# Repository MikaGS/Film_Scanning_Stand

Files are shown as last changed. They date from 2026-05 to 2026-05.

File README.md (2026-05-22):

# Film Scanning Stand



A modular DIY film scanning stand for digitizing 35mm and medium format negatives using a mirrorless camera.

The system uses aluminium extrusions, a linear rail, leveling parts and a camera carrier. It is designed for repeatable alignment, precise camera height adjustment, and high-resolution scans of larger formats such as 6x7 and 6x12. 

## Features

- Adjustable camera height on linear rail
- Aluminium extrusion frame
- Mirrorless camera support
- Compatible with 35mm, 6x7 and 6x12 film
- Custom 3D-printed film holders
- Designed for stitched high-resolution scans
- Modular and repairable construction

## Current Status

Prototype / work in progress.
Stand is working, automation with steppers, etc. in progress

## Documentation

- [Build Guide](docs/build-guide.md)
- [Camera Setup and Calibration](docs/camera-setup.md)
- [Film Holders](docs/film-holders.md)
- [Parts List](bom/parts-list.md)

## License

This project is shared for personal, educational and non-commercial DIY use.

You may build, modify and share this project for non-commercial purposes, but you may not sell printed parts, kits, CAD files, drawings, assembled versions or derivatives of this design without written permission.

See [LICENSE.md](LICENSE.md) for details.

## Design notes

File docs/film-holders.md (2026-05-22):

# Film Holders

This document describes the film holder system used with the modular film scanning stand.

The holders are designed to keep the film flat, aligned and repeatable during camera scanning. Different holders can be used for 35mm film and medium format negatives such as 6x7 and 6x12.

## Design Goals

- Hold the film flat during scanning
- Keep the film plane repeatable
- Reduce reflections from the light source
- Allow accurate stitching of larger negatives
- Use simple 3D-printed parts
- Be easy to modify for different film formats

## Supported Formats

| Format | Notes |
|---|---|
| 35mm | Single-frame scanning |
| 6x7 | Medium format scanning |
| 6x12 | Stitched panoramic scanning |

## Holder Construction

The film holder consists of two main parts:

- a lower base part
- an upper clamping part

The lower part defines the film position and scanning window.  
The upper part holds the film down and helps keep it flat.

The two parts are aligned using metal pins.

## Alignment Pins

Metal pins are used to keep the film holder aligned between scans.

The first pair of pins defines the X-position.  
A second pair of pins helps control rotation while still allowing controlled tolerance in the Y-direction if needed.

This makes the holder repeatable while avoiding unnecessary stress on the printed parts or the film.

## Film Flatness

Film flatness is created by pressing the film between the upper and lower holder parts.

Screws can be used to apply light pressure.

The film should be held flat, but not so tightly that it scratches or bends.

## Scanning Window

The scanning window is smaller than the complete negative area in some holder versions.

This helps reduce unwanted reflections and improves contrast during scanning.

For stitched scans, the film can be scanned in multiple overlapping sections.

## 6x12 Scanning

The 6x12 holder is designed for stitched scanning.

Instead of capturing the whole negative in one image, the film is scanned in multiple overlapping shots. This allows higher resolution and better use of the camera sensor.

Typical workflow:

1. Place the film in the holder.
2. Align the first scanning position.
3. Capture the first image.
4. Move the camera or film holder to the next position.
5. Capture the overlapping image.
6. Repeat until the full negative is covered.
7. Stitch the images in software.

## Material

The holders are 3D printed.

Recommended materials:

- PETG
- ABS / ASA
- stiff carbon-filled filament

For this build, Extrudr GreenTEC Pro CF was used.

A matte black material is recommended to reduce reflections.

## Notes

Avoid glossy surfaces near the film or scanning window.

If reflections appear in the scan, reduce the window size, add matte black surfaces, or increase the distance between the film and reflective parts.

The holder design may need to be adjusted depending on the exact light source, camera setup and scanning format.

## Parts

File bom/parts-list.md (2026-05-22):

# Parts List

This list contains the main mechanical and printed parts required to build the modular film scanning stand.

Quantities and lengths may depend on the final CAD model and the desired scanning height.

## Main Components

| Part | Quantity | Notes |
|---|---:|---|
| Aluminium extrusion | as needed | Cut to the desired length |
| Linear rail, 300 mm | 1 | Mini linear rail with 2 carriage blocks |
| MGN12H carriage blocks | 2 | Usually included with the rail |
| Lead screw | 1 | Length depends on the CAD model |
| Lead screw nut | 2 | for precise movement |
| Lead screw coupling | 1 | For connecting the stepper motor to the lead screw |
| Bearing for lead screw | 1 | Used in the top bearing mount |
| Stepper motor | 1 | For height adjustment and holding force |
| Camera leveling plate | 1 | For fine camera alignment |
| Panorama head / panorama plate | optional | Useful for better leveling and rotational alignment |
| Arca-Swiss quick release clamp | optional | For easier camera mounting and removal |
| Base plate | 1 | Siebdruckplatte or another stable board |
| Black acrylic sheet | optional | For laser-cut covers, panels or finishing parts |

## Fasteners and Hardware

| Part | Quantity | Notes |
|---|---:|---|
| M3 screws | as needed | Used for linear rail and smaller printed parts |
| M4 screws | as needed | Used for medium-strength printed connections |
| M5 screws | as needed | Used for adapters to aluminium extrusion |
| M5 slot nuts / T-nuts | as needed | For mounting printed adapters to the aluminium extrusion |
| M5 × 6 mm wafer head screws | as needed | Low-profile mounting screws |
| M5 × 10 mm wafer head screws | as needed | For extrusion adapters or thicker printed parts |
| M4 × 8 mm wafer head screws | as needed | For printed parts or accessory mounting |
| 3/8" camera screws | as needed | For tripod plates, leveling plates or camera accessories |
| Heat-set inserts, M3/M4/M5 | as needed | I used short threaded inserts, e.g. CNC Kitchen inserts |

## 3D Printing

| Material | Notes |
|---|---|
| PETG | Easy to print, good general choice |
| ABS / ASA | Better heat resistance, harder to print |
| Extrudr GreenTEC Pro CF | Used for this build; stiff, carbon-filled material |
| Other stiff filament | Can be used if dimensions and strength are suitable |

## Printed Parts

| Printed Part | Notes |
|---|---|
| Linear rail adapters | Connect the rail to the aluminium extrusion |
| Top bearing mount | Holds the top lead screw bearing |
| Top bearing lid | Secures the bearing in place |
| Bottom support | Lower support for the lead screw / extrusion |
| Camera carrier, first half | Mounts to the linear rail carriages |
| Camera carrier, second half | Holds the leveling plate / camera mount |
| Optional covers or spacers | Depending on the final CAD design |

## Optional Laser-Cut Parts

| Part | Material | Notes |
|---|---|---|
| Side panels | Black acrylic | Optional visual or structural finishing parts |
| Covers | Black acrylic | Can be used to hide mechanics or improve appearance |
| Alignment plates | Acrylic or plywood | Optional aids for assembly and calibration |

## Notes

Check the final CAD model before ordering the lead screw, aluminium extrusion and acrylic parts.

Some screw lengths may need to be adjusted depending on the printed part thickness, insert depth and accessory stack-up.

For the base plate, a stable and flat material is recommended. A Siebdruckplatte or another rigid wooden board works well.

## Related Parts Lists

- [Film Holder Parts List](film-holder-parts-list.md)

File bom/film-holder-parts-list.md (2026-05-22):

# Film Holder Parts List

This list contains the parts required for the 3D-printed film holders.

Quantities may depend on the number of film holders and supported formats.

## Main Components

| Part | Quantity | Notes |
|---|---:|---|
| 3D-printed film holder parts | as needed | Lower base and upper clamping parts |
| 2 mm × 22 mm cylindrical pins | as needed | Used for alignment between holder parts |
| M4 heat-set inserts | as needed | I used CNC Kitchen threaded inserts |
| M4 screws | as needed | Used to clamp or assemble the holder |
| M4 × 8 mm wafer head screws | as needed | Low-profile option for the film holder |
| Filament | as needed | PETG, ABS, ASA or stiff carbon-filled filament |

## Recommended Material

For this build, **Extrudr GreenTEC Pro CF** was used.

A matte black, stiff material is recommended because it helps reduce reflections around the scanning window and keeps the holder dimensionally stable.

## Notes

The cylindrical pins are used for repeatable alignment of the upper and lower film holder parts.

Screw lengths may need to be adjusted depending on the printed part thickness and the depth of the heat-set inserts.

Avoid glossy materials near the film window, since they can cause reflections during scanning.

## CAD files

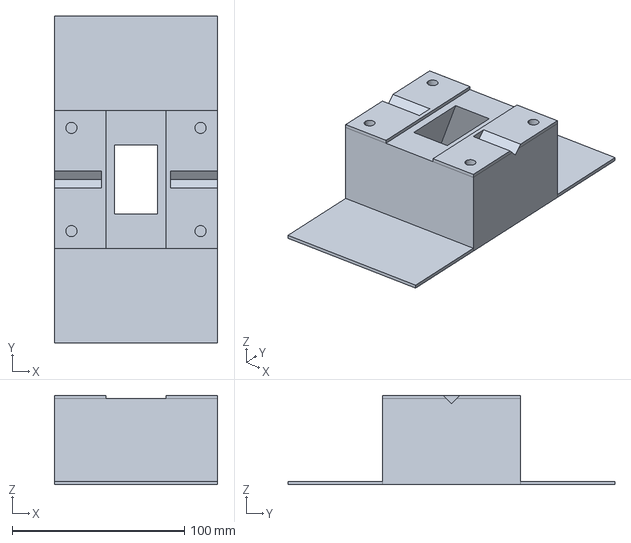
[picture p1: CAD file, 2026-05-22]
3D files/35mm_Holder_1.stp
95.0 x 190.0 x 52.0 mm

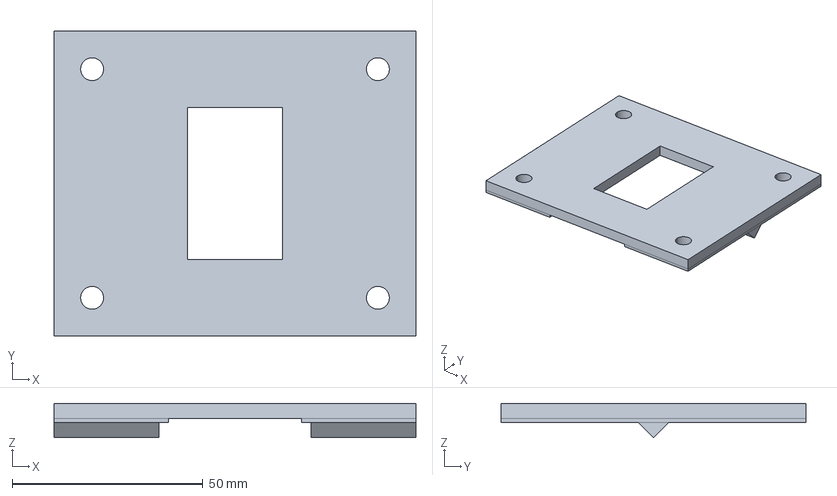
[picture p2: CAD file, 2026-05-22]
3D files/35mm_Holder_2.stp
95.0 x 80.0 x 9.00 mm

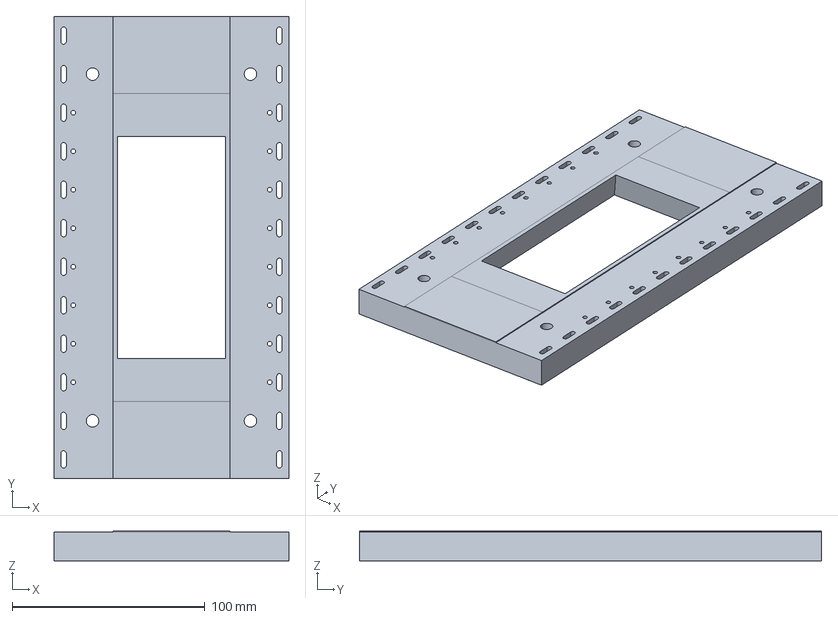
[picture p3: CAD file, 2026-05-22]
3D files/6x12_Holder_2.stp
122.0 x 240.0 x 15.5 mm

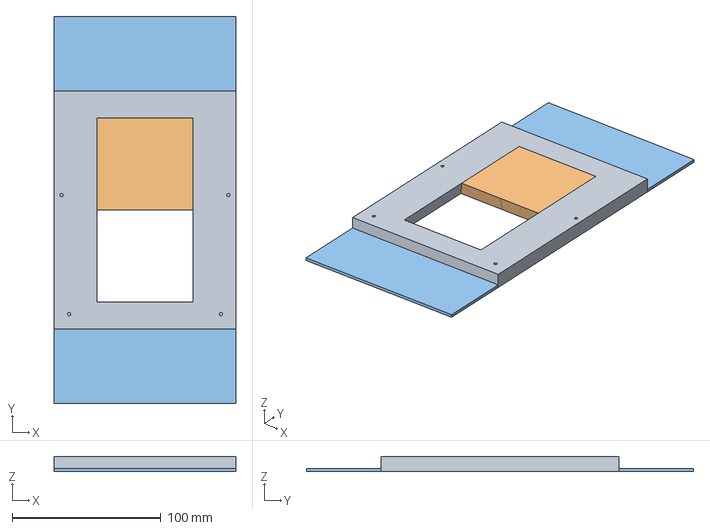
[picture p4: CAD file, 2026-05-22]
3D files/6x12_Holder_1.stp
122.0 x 260.0 x 10.0 mm

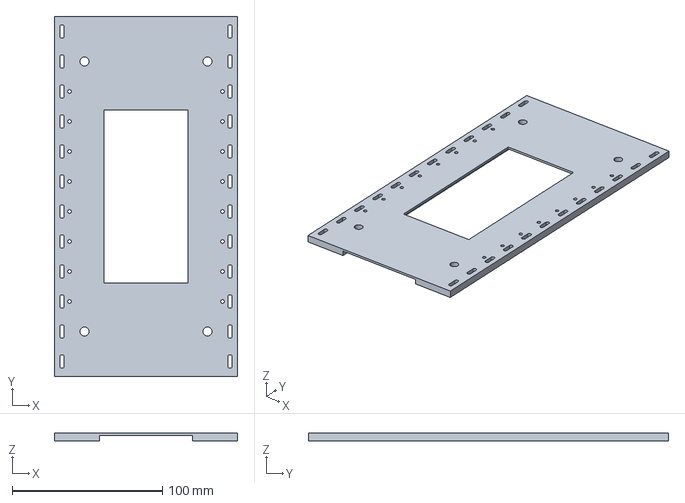
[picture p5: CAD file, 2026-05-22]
3D files/6x12_Holder_3.stp
122.0 x 240.0 x 5.00 mm

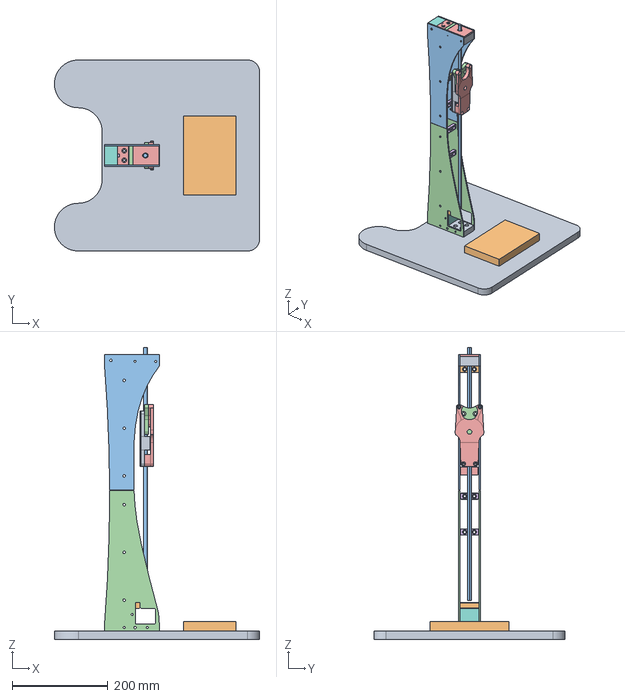
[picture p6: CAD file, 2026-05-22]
3D files/Scanning_Stand_V1.stp
429.6 x 400.0 x 611.5 mm

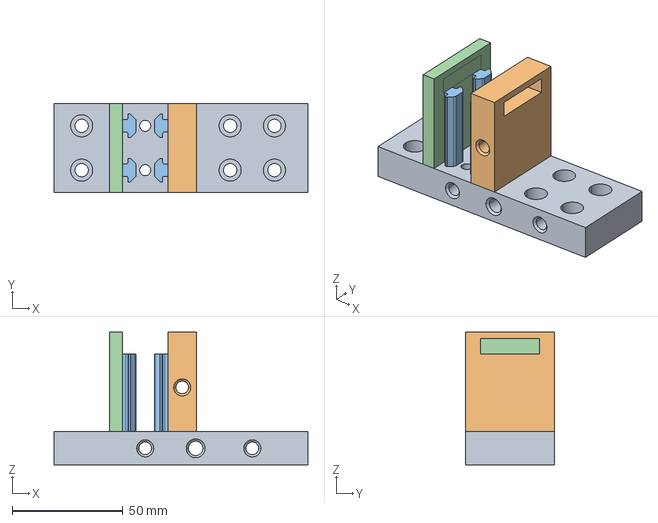
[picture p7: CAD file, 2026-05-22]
3D files/Bottom_support.stp
114.7 x 40.0 x 60.0 mm

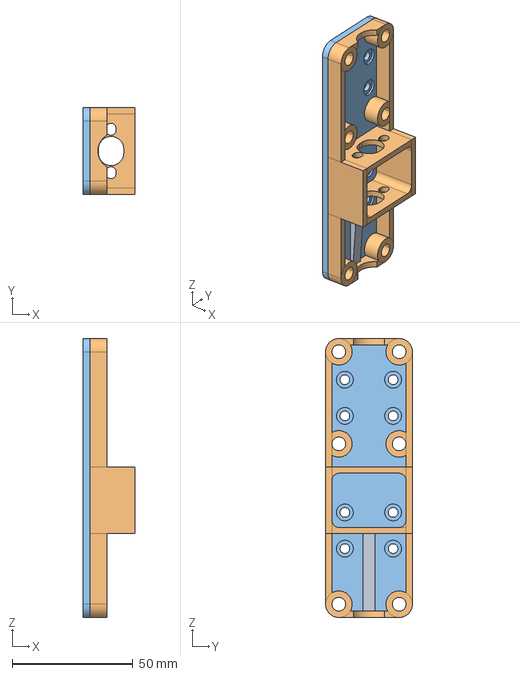
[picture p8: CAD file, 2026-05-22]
3D files/Camera_carrier_1.stp
21.7 x 36.0 x 115.6 mm

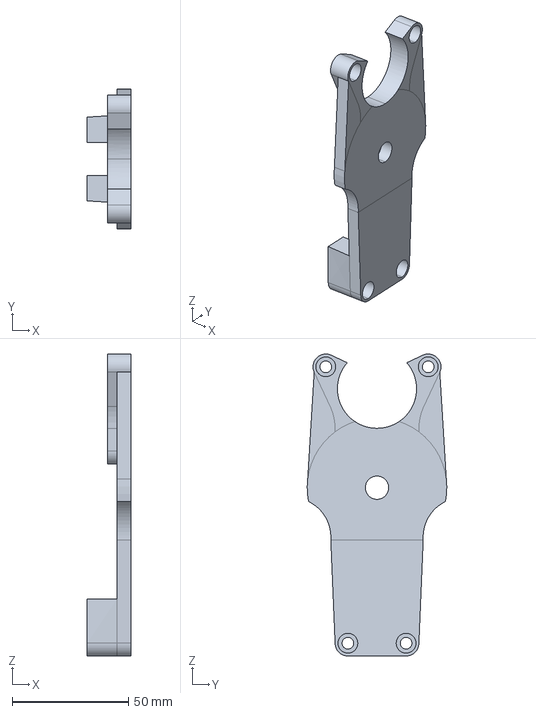
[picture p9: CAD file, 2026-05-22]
3D files/Camera_carrier_3.stp
18.7 x 60.0 x 129.7 mm

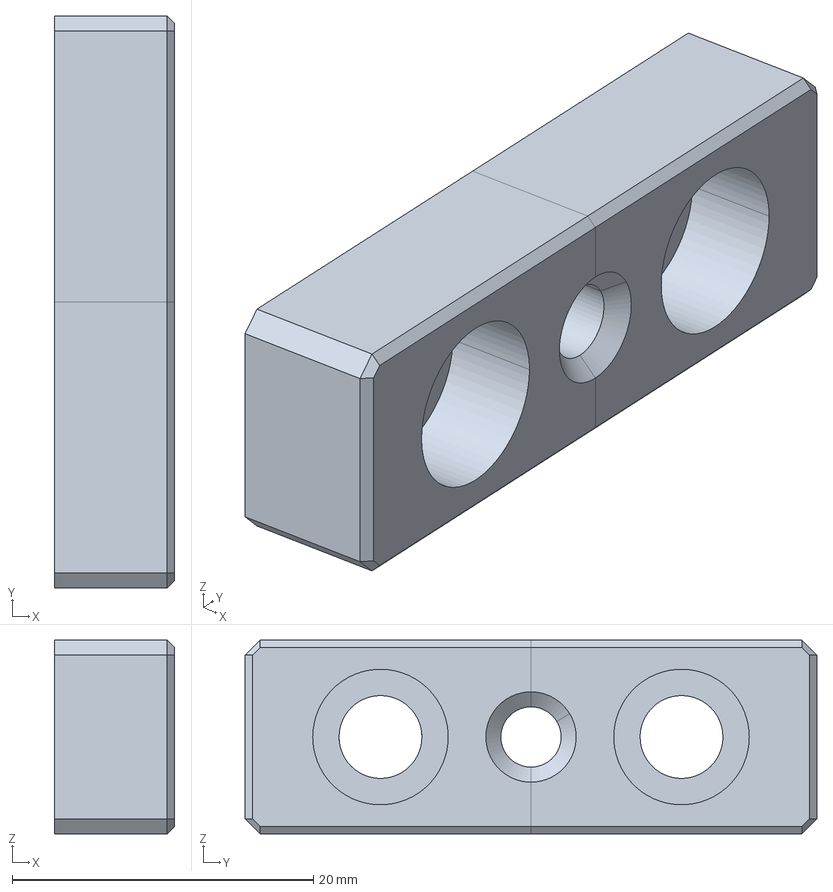
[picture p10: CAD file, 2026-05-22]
3D files/Linear_rail_adapters.stp
8.00 x 38.0 x 12.9 mm

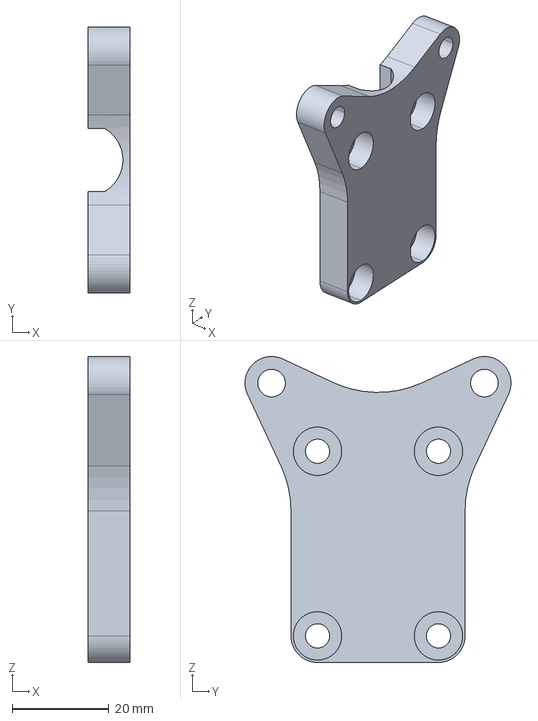
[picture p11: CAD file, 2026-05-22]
3D files/Camera_carrier_2.stp
8.75 x 55.0 x 63.3 mm

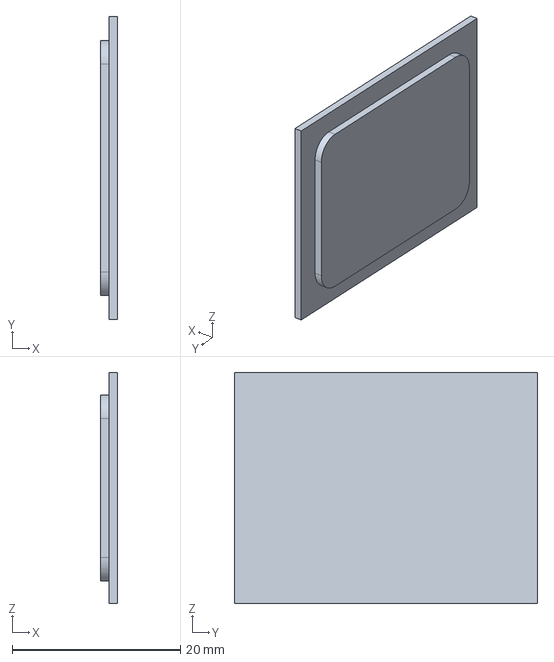
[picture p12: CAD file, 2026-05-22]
3D files/lid_grease.stp
2.00 x 36.0 x 27.5 mm

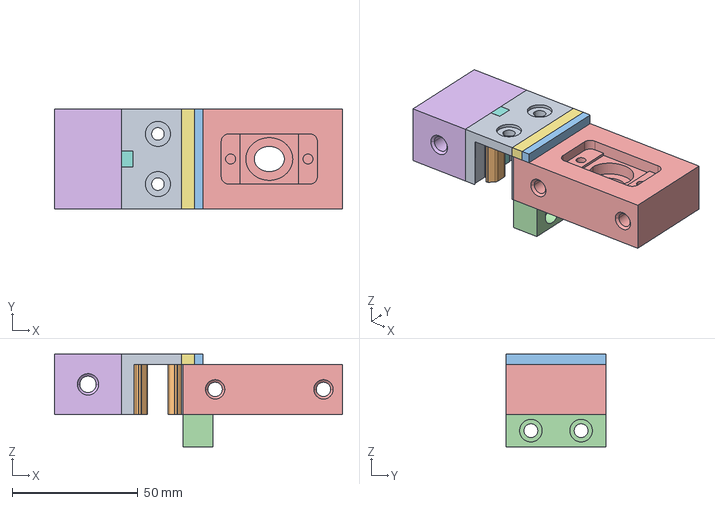
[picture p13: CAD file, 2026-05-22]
3D files/Top_bearing_mount.stp
114.7 x 40.0 x 36.9 mm

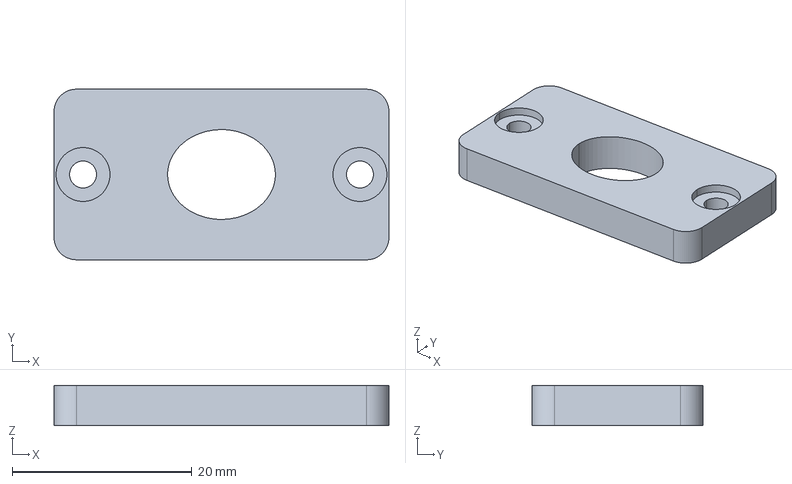
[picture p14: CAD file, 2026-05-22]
3D files/Top_bearing_lid.stp
37.3 x 19.0 x 4.50 mm

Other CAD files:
3D files/drilling_jig.stp

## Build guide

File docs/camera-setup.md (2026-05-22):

# Camera Setup

This document describes the camera setup used with the modular film scanning stand.

The stand is designed for camera-based film digitization of 35mm and medium format negatives. The system can be adapted to different cameras, lenses and film formats.

## Camera

For this build, a mirrorless camera is used for digitizing the negatives.

The camera is mounted to the camera carrier using a leveling plate, an optional panorama head and an optional Arca-Swiss quick release plate.

## Lens

A macro lens is recommended for film scanning.

The lens should be sharp, flat-field if possible, and able to focus close enough for the required reproduction ratio.

## Mounting Stack

Typical mounting order:

1. Camera carrier
2. Camera leveling plate
3. Optional panorama head
4. Optional Arca-Swiss quick release clamp
5. Camera

The leveling plate is used to align the camera parallel to the film plane.

The panorama head can be useful for fine rotational adjustment.

The Arca-Swiss quick release clamp makes it easier to mount and remove the camera without changing the main setup.

## Camera Settings

Recommended starting settings:

| Setting | Recommendation |
|---|---|
| File format | RAW |
| ISO | Base ISO |
| Aperture | f/5.6 to f/8 |
| Focus | Manual focus |
| White balance | Fixed manual white balance |
| Stabilization | Off when mounted rigidly |
| Shutter | Self-timer, remote release or electronic shutter |
| Exposure | Manual |

Avoid auto exposure and auto white balance, since they can create inconsistencies between scans.

## Focus

Focus manually on the film grain.

Use live view magnification if available.

After focusing, avoid touching the lens or camera unless the setup is recalibrated.

## Light Source

Use a stable, diffused and even light source.

The light should cover the full film area without visible hotspots or color shifts.

For color negative film, a high-quality light source with good color rendering is recommended.

## Scanning Workflow

1. Clean the film.
2. Place the film in the holder.
3. Turn on the light source and let it stabilize.
4. Set camera exposure manually.
5. Focus on the film grain.
6. Capture the scan.
7. For larger formats, capture overlapping images for stitching.
8. Export or process the RAW files in the preferred software.

## Notes

Keep the camera, lens, film holder and light source fixed during a scanning session.

For stitched scans, do not change exposure, focus or white balance between frames.

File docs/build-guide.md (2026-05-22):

# Build Guide

This guide describes the assembly process of the modular film scanning stand.

## 1. Print All Parts

Start by 3D printing all required parts for the frame adapters, top bearing mount, bottom support, camera carrier, servo mount and optional accessories.

After printing, remove all support material and clean the screw holes if necessary.

## 2. Install Heat-Set Inserts

Install the required heat-set inserts into the printed parts.

Use:

- M3 inserts for smaller mechanical connections and the linear rail mounting points
- M4 inserts where medium-strength connections are required
- M5 inserts for the adapters that connect to the aluminium extrusion

Make sure the inserts sit straight and flush with the printed surface.

## 3. Assemble the Aluminium Extrusion and Linear Rail

Attach the linear rail to the aluminium extrusion using the 3D-printed rail adapters.

The rail is mounted to the adapters with M3 screws.  
The adapters are mounted to the aluminium extrusion with M5 screws and slot nuts / T-nuts.

### Steps

1. Insert the M5 slot nuts into the aluminium extrusion.
2. Position the 3D-printed adapters on the extrusion.
3. Loosely attach the adapters with M5 screws.
4. Place the linear rail onto the adapters.
5. Attach the rail to the adapters using M3 screws.
6. Align the rail parallel to the aluminium extrusion.
7. Tighten all screws gradually.
8. Move the linear rail carriage through the full travel distance to check for smooth movement.

If the carriage binds or feels rough, loosen the screws slightly, realign the rail and tighten again.

## 4. Assemble the Top Bearing Part

Insert the bearing into the top printed part.

After the bearing is seated correctly, screw on the lid to hold the bearing in place.

Then attach the complete top bearing assembly to the aluminium extrusion.

## 5. Assemble the Bottom Part

Assemble the bottom printed part and attach it to the aluminium extrusion.

This part is designed as a press-fit connection. Carefully press it onto the extrusion until it is fully seated.

Make sure it sits straight, since it defines the lower support point for the lead screw.

## 6. Prepare the Camera Carrier

Install the nuts for the lead screw into the first half of the camera carrier they should be able to move.

Make sure the nuts are aligned correctly so that the lead screw can rotate smoothly without binding.

## 7. Attach the Camera Carrier to the Linear Rail

Attach the first half of the camera carrier to the linear rail carriages using eight M3 screws.

Tighten the screws evenly so the carrier sits flat against the rail carriages.

Check that the carrier can move smoothly along the rail.

## 8. Add Grease

Add a small amount of grease into the dedicated grease compartment.

This helps lubricate the lead screw and improves the smoothness of the height adjustment.

Do not overfill the compartment.

## 9. Attach the Carrier Grease compartment Lid

Attach the lid to the first half of the camera carrier.

## 10. Mount the Camera Leveling Plate

Mount the camera leveling plate to the second half of the camera carrier.

This plate will be used to fine-adjust the camera alignment during scanning.

Make sure it is securely attached, since camera stability is important for sharp scans and accurate stitching.

## 11. Join the Camera Carrier Halves

Attach the second half of the camera carrier to the first half.

Check that all screw holes align correctly and tighten the screws evenly.

The camera carrier should now be rigid, but still move freely along the linear rail.

## 12. Install the Lead Screw

Screw the lead screw through the top bearing, the camera carrier nuts and into the bottom support.

Rotate it slowly by hand to make sure it runs smoothly.

If there is resistance, check the alignment of the top bearing, bottom support and lead screw nuts.

## 13. Attach the Stepper Motor

Attach the stepper motor to the printed motor mount.

Connect the stepper motor to the lead screw using the coupling or drive mechanism, depending on the final design.

Make sure the motor shaft is aligned with the lead screw. Misalignment can cause binding, increased wear or uneven movement.

## 14. Optional: Short the Stepper Motor Leads

To increase passive holding resistance when the motor is not powered, the stepper motor phases can be shorted together.

This makes the motor harder to turn by hand and helps prevent the camera carrier from moving unintentionally.

Only short the stepper motor leads when the motor driver is disconnected or when the driver circuit is designed for this use.

Do not short the outputs of a powered stepper driver.

## 15. Attach the Stand to the Base

### Add Feet to the Base

Attach the feet to the base plate to improve stability and to protect the work surface.

### Attach the Stand to the Base

Place the assembled vertical stand onto the base plate and align it carefully.

Make sure the aluminium extrusion is perpendicular to the base and positioned so the camera carrier can move freely without hitting the base or light source.

### Steps

1. Position the assembled stand on the base plate.
2. Mark the mounting hole positions.
3. Drill pilot holes into the base plate.
4. Align the stand with the drilled holes.
5. Screw the stand securely onto the base plate.
6. Check that the vertical extrusion is straight and does not wobble.
7. Verify that the camera carrier can move through the full travel range.

If necessary, use a square or angle gauge to check that the vertical stand is mounted at 90° to the base.

## 16. Add Optional Parts

Optional accessories can be added depending on the scanning workflow and required adjustment precision.

### Panorama Head

A panorama head can be mounted between the camera carrier and the camera leveling plate.

This allows finer rotational adjustment and makes it easier to align the camera perfectly parallel to the film plane. It is especially useful for stitched scans of larger formats such as 6x7, 6x9 or 6x12.

### Arca-Swiss Quick Release Plate

An Arca-Swiss quick release plate can be added for faster camera mounting and removal.

This makes it easier to switch cameras, remove the camera for other use, or reposition the camera without fully disassembling the scanning setup.

Make sure the quick release plate is mounted securely and does not introduce flex or unwanted movement.

### Optional Laser-Cut Pieces

If used, add the optional laser-cut pieces at this stage.

These can be used for additional stiffness, covers, alignment aids, or visual finishing parts.

Make sure they do not interfere with the movement of the camera carrier or the lead screw.

## Final Check

Before mounting the camera, check the full mechanical movement:

- The carrier moves smoothly along the full rail travel
- The lead screw turns without binding
- The stepper is properly aligned
- The aluminium extrusion and rail are rigidly connected
- The camera leveling plate is secure
- All screws are tightened
- No printed part is under unwanted stress

The stand is now ready for camera mounting and calibration.
